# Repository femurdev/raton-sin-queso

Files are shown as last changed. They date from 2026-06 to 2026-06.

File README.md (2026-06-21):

# Ratón Sin Queso
*A mouse without cheese* 
- Onshape Document: https://cad.onshape.com/documents/3eceed79fd8189f0e7238951
# Where is it
A mouse whose hardware was hand-picked to squeeze as much performance out of it as possible. It is not light and not cheap, but I’ve got forearms so that don’t matter. As of writing this, I have it working over a wired connection but plan to implement Bluetooth protocols in the coming days.
## Who is it
I’m Femurdev, a recent high school graduate who’s excited about all things electronics, code, and research.
## Why is it
Back at the end of the school year, my trusty mouse broke. Since then, I have repaired it, but got me wondering if I could build a mouse with top of the line hardware and also make my own pcbs for it. I wanted to see if I could create an ergonomic gaming mouse for people with larger hands.
## Specs
8 side buttons, 3 indicator led, LMB, RMB, standard TTC encoder and MMB switch. Uses an nRF52 module from Seeed Studio for usb and Bluetooth compatibility.
IMG_4938 Background Removed

## Usage & construction guide
- Print the 3D models in the repo, one of each. I made mine of PLA.
- Order the parts listed in the BOM.
- Construct the pcbs as according to the BOM.
- Place all parts on the bottom chassis.
- Glue the buttons to the top of them. They should remain about 2.2 mm above the shell when glued. 
- The flexibility of the PLA provides the spring back effect.
- Make connections as described in the kicad files. Connect your in place pcbs via the screw terminals. 
- If you’re using a TTC encoder as recommended, solder these jumpers.

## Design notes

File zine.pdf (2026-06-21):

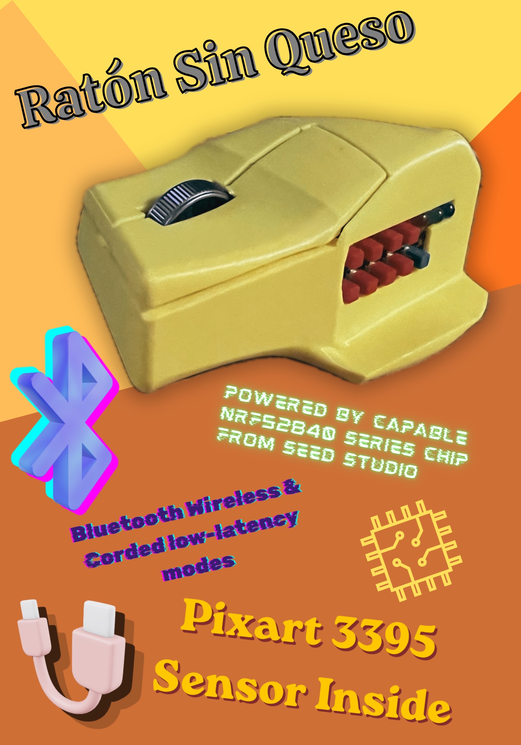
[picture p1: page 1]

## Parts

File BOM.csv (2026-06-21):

Category | Ref(s) | Item / Description | Spec / Value | Qty Used | Qty Bought | Source / Store | Status | Unit Cost | Order Total | Notes
Core electronics | U1 | MINI nRF52840 Bluetooth 5.0 Development Board | Type-C, QSPI flash, ~18x21mm | 1 | 1 | AliExpress — Uncle Electronic Tech Store | Purchased | $8.06 | $9.34 | Official/Seeed-style nRF52 module; main MCU/BLE
Sensor | Sensor module | PAW3395DM-T6QU optical displacement module | PAW3395 module | 1 | 1 | AliExpress — Optical Sensor Store | Purchased | $24.17 | $31.68 | SPI sensor module; verify 3V3/GND/SCK/MOSI/MISO/CS/MOTION pinout
GPIO expander | U3 | MCP23017 I2C GPIO expander | DIP-28 | 1 | 1 | Digi-Key / Mouser / AliExpress | Need / verify |  |  | Side PCB: 9 side buttons + MMB + LEDs; address A0-A2 = GND
Main clicks | SW1, SW2 | Kailh Blue GM 8.0 mouse microswitches | 3-pin mouse switch | 2 | 4 | AliExpress — It's a good price Store | Purchased | $1.00 | $4.61 | LMB/RMB; use COM->GND, NO->GPIO
Side/MMB buttons | SW3-SW12 | Kailh 6x6x7.3 square silent micro switch | 10 pcs | 10 | 10 | AliExpress — Hrui franchise Store | Purchased but footprint mismatch risk | $0.19 | $2.19 | PCB footprint issue noted; may replace with matching 6x6x7.3 THT tact switches
Side/MMB buttons alt | SW3-SW12 | 6x6mm THT tactile switch, 7.3mm actuator height | SPST-NO, 4-pin | 10 | 10 | Digi-Key | Recommended fix |  |  | Choose parts matching KiCad SW_PUSH_6mm_H7.3mm footprint
Scroll encoder | U2 | TTC mouse encoder / decoder | 11mm, Green/Red core | 1 | 2 | AliExpress — Passionate girl Store | Purchased | $0.90 | $2.07 | Direct to MCU; A/B with 10k or 20k pullups; COM->GND
Scroll wheel | Mechanical | Mouse scroll wheel pulley | G Pro / G Pro X Superlight style, purple | 1 | 1 | AliExpress — DREAM Store | Purchased | $6.16 |  | Verify 1.74mm axle/hole compatibility
Power switch | SW_PWR | SPDT mini micro slide switch | 1P2T, 2-position, 3-pin, handle length assortment | 1 | 60 | AliExpress — LOLOIY Store | Purchased | $0.08 | $8.22 | Battery BAT+ -> switch -> MCU BAT+
Battery | BAT1 | 1S LiPo battery | 803048 target size; 3.7V nominal, 4.2V full | 1 | 1 | Ordered separately | Ordered |  |  | 1200mAh realistic for 803048; 80mAh test battery temporary
Main PCB | PCB1 | Ratón Sin Queso main PCB | 2-layer FR4 | 1 | 5 | JLCPCB | Need fab/ordered? |  |  | Recommended: 1.6mm, 1oz, lead-free HASL, tented vias
Side PCB | PCB2 | Ratón Sin Queso side-button PCB | 2-layer FR4 | 1 | 5 | JLCPCB | Need fab/ordered? |  |  | Can be 1.0-1.6mm; has MCP23017/buttons/LEDs
Capacitors | C1-C4 | Ceramic decoupling capacitors | 0.1µF, 1206 hand-solder | 4 | 4 | Parts kit / Digi-Key | Need / verify |  |  | Place near MCP23017, sensor connector/module, rails
Bulk capacitor | C_bulk | Bulk rail capacitor | 47µF, 10V | 1 | 1 | Parts kit / Digi-Key | Need / verify |  |  | Side PCB 3V3 rail near connector; polarity if electrolytic
LEDs | D1-D3 | Through-hole LEDs | Red, Green, Blue; 5mm body, ~3mm lead spacing | 3 | 3 | Starter kit / Digi-Key | Have / verify |  |  | Red=low batt/error, Green=connected, Blue=pairing
LED resistors | R17-R19 | LED current-limit resistors | 2.2kΩ | 3 | 3 | Starter kit | Need / verify |  |  | You considered 4.7k too; 2.2k brighter. One resistor per LED
Pullups | R1-R6 | Pullup resistors | 10kΩ THT DIN0207 | 6 | 6 | Starter kit | Need / verify |  |  | I2C SDA/SCL, INT, reset, encoder or button pullups as routed
Encoder pullups | R_encA/R_encB | Encoder pullup resistors | 10kΩ or 20kΩ | 2 | 2 | Starter kit | Have |  |  | 20k acceptable for encoder A/B
Screw terminals | J1 | 2-pin screw terminal | 3.50mm pitch | 1 | 1 | Parts kit / AliExpress | Need / verify |  |  | Battery or power connection
Screw terminals | J2-J4 | 6-pin screw terminal | 3.50mm pitch | 3 | 3 | Parts kit / AliExpress | Need / verify |  |  | Inter-board/sensor connectors depending PCB layout
Jumper pads | JP2-JP11 | 2-pad solder jumper/test point | 2.54mm pitch | 10 | 10 | PCB footprint | On PCB | $0.00 | $0.00 | Encoder remap / optional INT links
Wire | W1 | Flexible hookup wire | 30AWG silicone recommended | 1 | 1 | AliExpress / kit | Need / verify |  |  | Internal connections, bodges, sensor/side PCB as needed
Fasteners | M2 hardware | M2 screws / heat-set inserts | For PCB/shell mounting | 1 | 1 | AliExpress / kit | Need / verify |  |  | Mount main PCB, side PCB, wheel support
Mouse feet | Feet | PTFE mouse skates / sheet | Universal PTFE | 1 | 1 | AliExpress | Need / verify |  |  | Important for feel
Mechanical | Wheel support | Passive scroll-wheel support fork | 3D printed | 1 | 1 | Custom print | Need design/print |  |  | Opposite side of TTC encoder; supports axle
Mechanical | Shell | Mouse shell | 3D printed / custom | 1 | 1 | Custom print | Need design/print |  |  | Must set PAW3395 module height and wheel geometry
Graphics | Silkscreen art | Ratón Sin Queso logo graphics | B/W bitmap/SVG | 1 | 1 | Generated assets | Done | $0.00 | $0.00 | Use simplified icon for PCB; crowned mascot for docs/stickers

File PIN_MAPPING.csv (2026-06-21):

MCU Pin | Function | Notes
D0 | Encoder A | Direct GPIO input with pullup
D1 | Encoder B | Direct GPIO input with pullup
D2 | LMB | COM->GND, NO->D2; direct GPIO
D3 | RMB | COM->GND, NO->D3; direct GPIO
D4 | I2C SDA | To MCP23017; pullup to 3.3V
D5 | I2C SCL | To MCP23017; pullup to 3.3V
D6 | Shared INT | MCP23017 INTA + optional PAW3395 MOTION via jumper; pullup to 3.3V
D7 | PAW3395 CS/NCS | SPI chip select
D8 | PAW3395 SCK | SPI clock
D9 | PAW3395 MISO/SDO | Sensor -> MCU
D10 | PAW3395 MOSI/SDI | MCU -> sensor
MCP GPA0-GPA7 | Side buttons 1-8 | Input pullups enabled, button to GND
MCP GPB0 | Side button 9 | Input pullup enabled, button to GND
MCP GPB1 | MMB | Input pullup enabled, button to GND
MCP GPB2-GPB4 | Red/Green/Blue LEDs | Output -> resistor -> LED anode; cathode -> GND

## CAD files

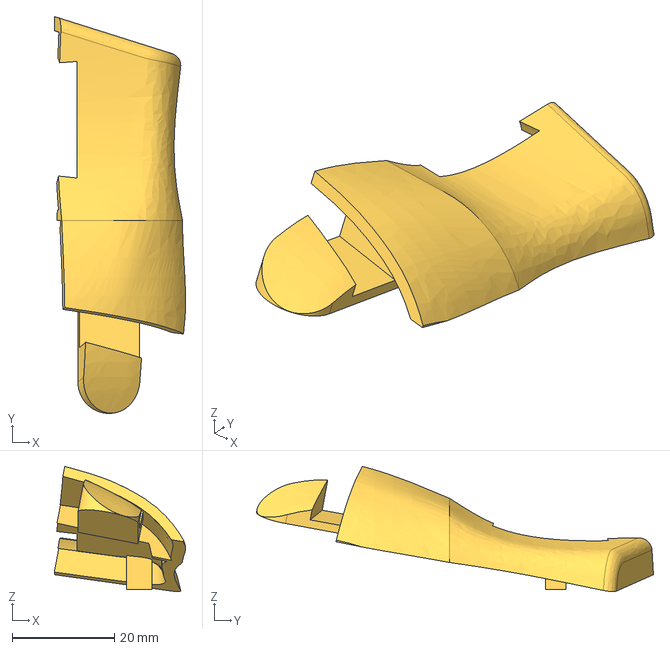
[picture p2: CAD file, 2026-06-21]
raton/Part Studio 1 - right_mouse_button.step
25.8 x 77.8 x 24.5 mm

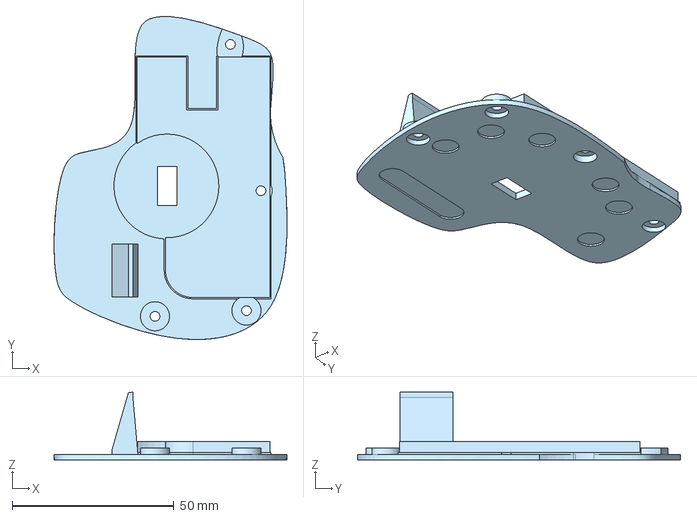
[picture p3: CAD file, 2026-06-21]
raton/Part Studio 1 - base_and_internals.step
72.0 x 99.8 x 20.9 mm

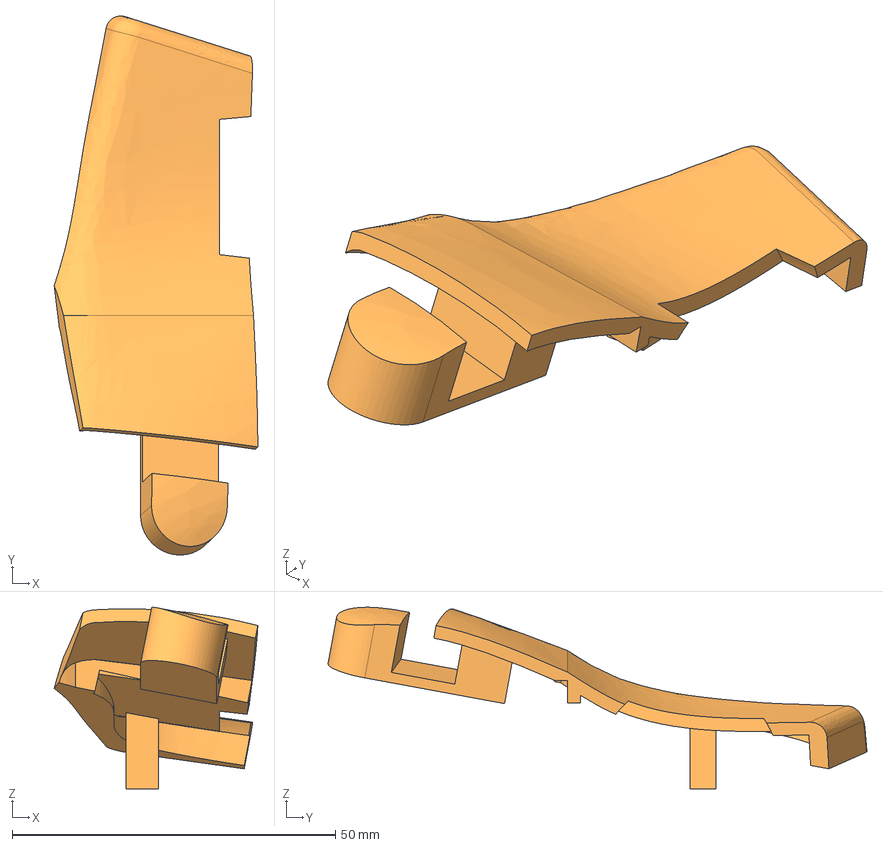
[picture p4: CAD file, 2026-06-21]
raton/Part Studio 1 - left_mouse_button.step
31.5 x 83.4 x 28.1 mm

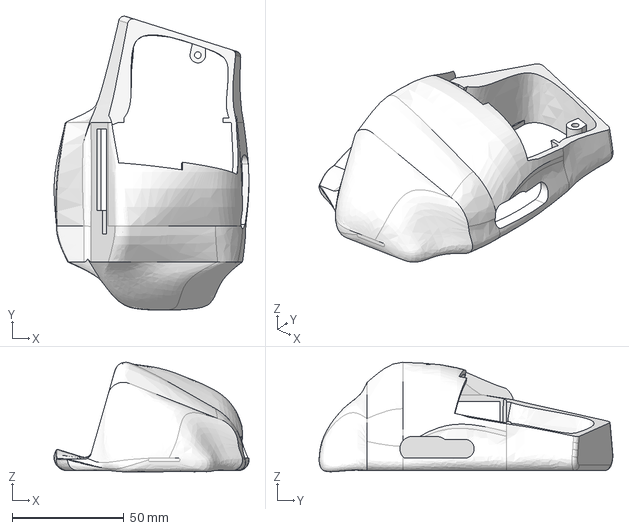
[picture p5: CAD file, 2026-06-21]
raton/Part Studio 1 - shell.step
87.4 x 131.7 x 49.1 mm

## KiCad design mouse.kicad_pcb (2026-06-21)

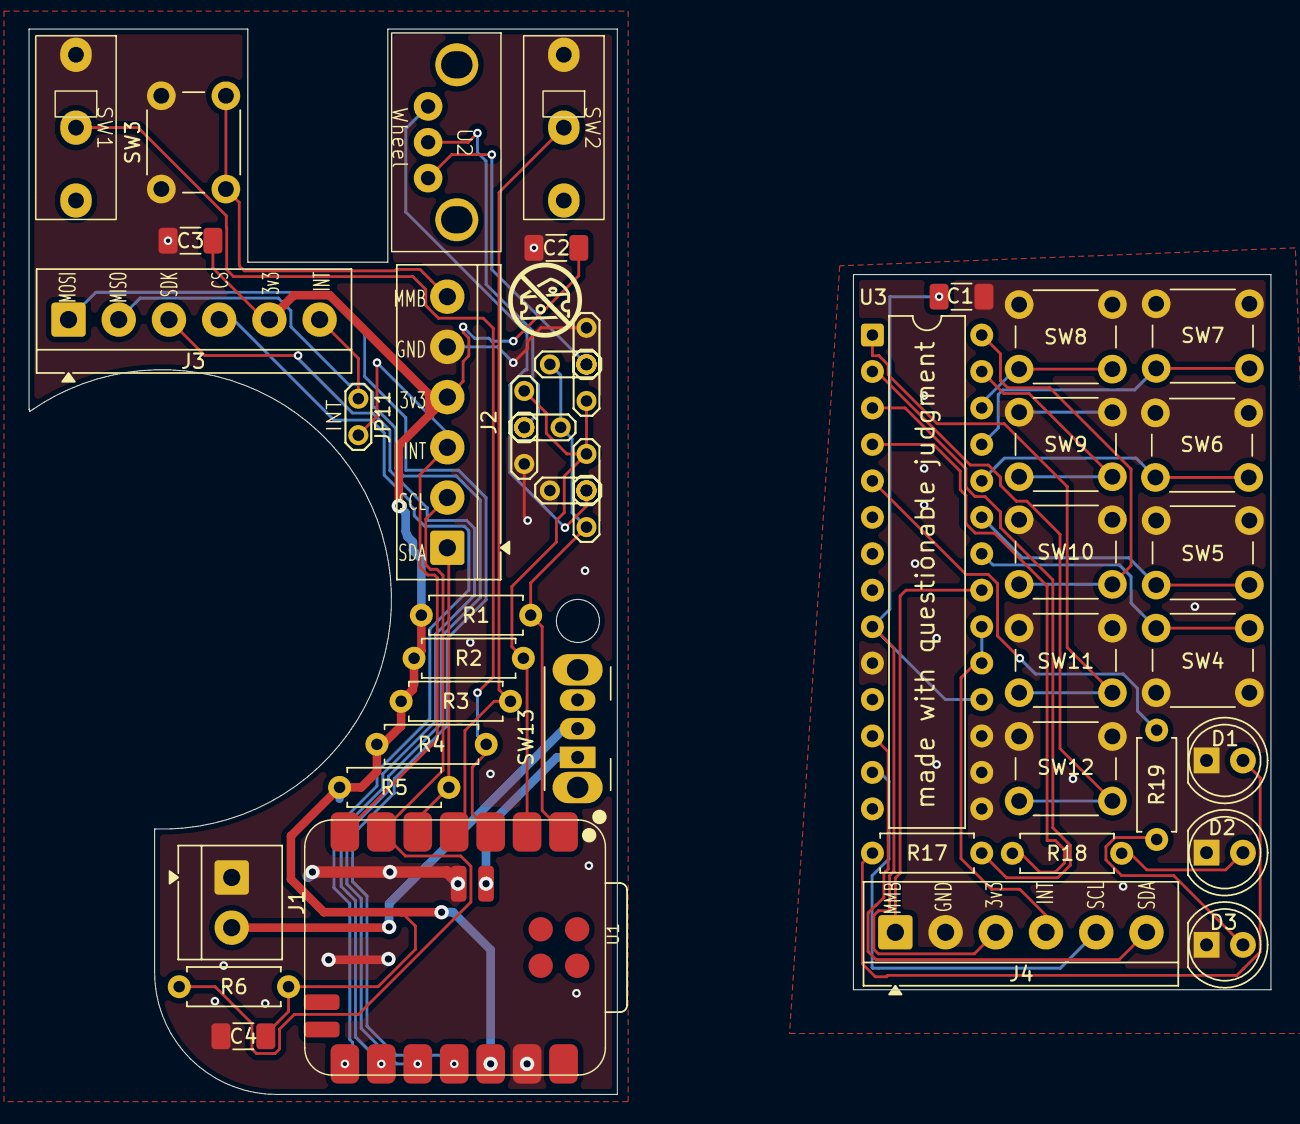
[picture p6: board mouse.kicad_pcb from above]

Board: 2 copper layers, 86.6 x 74.2 mm, 46 parts (0 on the bottom side), 39 nets.

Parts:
C1, C2, C3, C4: .1μ; C_1206_3216Metric_Pad1.33x1.80mm_HandSolder
D1, D2, D3: LED; LED_D5.0mm
J1: Screw_Terminal_01x02; TerminalBlock_4Ucon_1x02_P3.50mm_Horizontal
J2, J3, J4: Screw_Terminal_01x06; TerminalBlock_4Ucon_1x06_P3.50mm_Horizontal
JP2, JP3, JP4, JP5, JP6, JP7, JP8, JP9, JP10, JP11: Jumper_2_Open; TestPoint_2Pads_Pitch2.54mm_Drill0.8mm
R1, R2, R3, R4, R5, R6: 10k; R_Axial_DIN0207_L6.3mm_D2.5mm_P7.62mm_Horizontal
R17, R18, R19: 2.2k; R_Axial_DIN0207_L6.3mm_D2.5mm_P7.62mm_Horizontal
SW1, SW2: Kailh_Mouse_Switch
SW3, SW4, SW5, SW6, SW7, SW8, SW9, SW10, SW11, SW12: SW_Push; SW_Kailh_6x6x7.3_Silent
SW13: SW_SPDT; SW_Slide_SPDT_Angled_CK_OS102011MA1Q
U1: XIAO-nRF52840-SMD
U2: TTC_Scrollwheel_Encoder
U3: MCP23017x-x-SP; DIP-28_W7.62mm

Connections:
+3V3: C1.1, C2.1, C3.1, C4.1, J2.4, J3.5, J4.3, R1.1, R2.1, R3.1, R4.1, R5.1, R6.1, U1.12 (3V3), U3.9 (V_{DD}), U3.18 (~RESET)
+BATT: SW13.1 (A), U1.20
/Button Board/int: J4.4, U3.19 (INTB), U3.20 (INTA)
/Button Board/mmb: J4.1, U3.21 (GPA0)
/Button Board/scl: J4.5, U3.13 (SDA)
/Button Board/sda: J4.6, U3.12 (SCK)
/Button Board/sideButtonMMB1/SIGNAL: SW4.2, U3.22 (GPA1)
/Button Board/sideButtonMMB2/SIGNAL: SW5.2, U3.23 (GPA2)
/Button Board/sideButtonMMB3/SIGNAL: SW6.2, U3.24 (GPA3)
/Button Board/sideButtonMMB4/SIGNAL: SW7.2, U3.25 (GPA4)
/Button Board/sideButtonMMB5/SIGNAL: SW8.2, U3.26 (GPA5)
/Button Board/sideButtonMMB6/SIGNAL: SW9.2, U3.27 (GPA6)
/Button Board/sideButtonMMB7/SIGNAL: SW10.2, U3.28 (GPA7)
/Button Board/sideButtonMMB8/SIGNAL: SW11.2, U3.1 (GPB0)
/Button Board/sideButtonMMB9/SIGNAL: SW12.2, U3.2 (GPB1)
/LMB: R4.2, SW1.2 (NO), U1.3 (P0.28_A2_D2)
/RMB: R3.2, SW2.2 (NO), U1.4 (P0.29_A3_D3)
/enc_a: JP3.1 (A), JP6.1 (A), JP9.1 (A), R1.2, U1.1 (P0.02_A0_D0)
/enc_b: JP4.1 (A), JP7.1 (A), JP10.1 (A), R2.2, U1.2 (P0.03_A1_D1)
/int: J2.3, JP11.1 (A), U1.7 (P1.11_D6_TX)
/mmb: J2.6, SW3.2
/scl: J2.2, R6.2, U1.6 (P0.05_A5_D5_SCL)
/sda: J2.1, R5.2, U1.5 (P0.04_A4_D4_SDA)
GND: C1.2, C2.2, C3.2, C4.2, D1.1 (K), D2.1 (K), D3.1 (K), J1.1, J2.5, J4.2, JP2.1 (A), JP5.1 (A), JP8.1 (A), SW1.1 (COM), SW2.1 (COM), SW3.1, SW4.1, SW5.1, SW6.1, SW7.1, SW8.1, SW9.1, SW10.1, SW11.1, SW12.1, U1.13 (GND), U1.19, U3.10 (V_{SS}), U3.15 (A0), U3.16 (A1), U3.17 (A2)
unnamed: D1.2 (A), R17.2
unnamed: D2.2 (A), R18.2
unnamed: D3.2 (A), R19.2
unnamed: J1.2, SW13.2 (B)
unnamed: J3.1, U1.11 (P1.15_D10_MOSI)
unnamed: J3.2, U1.10 (P1.14_D9_MISO)
unnamed: J3.3, U1.9 (P1.13_D8_SCK)
unnamed: J3.4, U1.8 (P1.12_D7_RX)
unnamed: J3.6, JP11.2 (B)
unnamed: JP2.2 (B), JP3.2 (B), JP4.2 (B), U2.1 (A)
unnamed: JP5.2 (B), JP6.2 (B), JP7.2 (B), U2.3 (COM)
unnamed: JP8.2 (B), JP9.2 (B), JP10.2 (B), U2.2 (B)
unnamed: R17.1, U3.3 (GPB2)
unnamed: R18.1, U3.4 (GPB3)
unnamed: R19.1, U3.5 (GPB4)
